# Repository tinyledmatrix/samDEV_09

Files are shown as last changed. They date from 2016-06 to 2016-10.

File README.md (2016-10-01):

# samDEV_09
small test/development board for Atmels's SAMD09 ARM Cortex M0+ Microcontroller

see my [poject](https://hackaday.io/project/12099) on Hackaday.io for more information. 

I build this board to getting started with the SAMD microcontroller family after I made the mistake to try the much bigger SAMD21 first. The SAMD09 used here is he smallest from this family and therefore has the shortest (still 709 p.) datasheet. I think this board will be, as my other microcontroller breakout boards, very useful for an early prototyping phase on breadboard. So far I quite like the SAMD09. If you compare it to the the ATmegas there are a lot more possibilities. Maybe this is the Arduino Nano killer for me.
Features

    - 3.3V 0.8A LDO (1117-3.3)
    - powered from USB, Vin pin (3.6-13.8V) or regulated 3.3V
    - on board USB to serial bride IC (CH340)
    - reset switch
    - SWD programming header
    - optional 32kHz crystal (if not needed pins can be used as additional IOs)
    - on board user LED (connected to PA02)
    - on board power LED (connected to 3.3 rail)

###Partlist:

    Part   Value        Package     Comment          
    A08                 0603        User LED connected to PA08
    C1     100n         C0603       
    C2     15p          C0603       optional 
    C3     15p          C0603       optional 
    C4     10n          C0603       
    C5     100n         C0603       
    C7     100n         C0603       
    D1     MBR0520LT    SOD123      power selection diode
    D2     MBR0520LT    SOD123      power selection diode
    IC1    CH340G       SOIC16      USB-UART bridge
    IC2    1117-3.3     SOT223      LDO
    JP1                 1X08_OCTA   pin header
    JP2                 1X08_OCTA   pin header
    JP5                 2X05_1,27B  programming pin header 
    K1     mini USB     generic     Mini USB connector
    PWR                 0603 	Power LED
    Q1     3215         3215        optional external 32kHz crystal 
    Q2     CSTCRCSTCE   CSTCESMALL  12 MHz resonator for CH340G
    R1     solder / 0   R0201       PA08 - pin header
    R2     solder / 0   R0201       PA09 - pin header
    R3     120  / 220   R0603       resistor for power LED
    R4     120  / 220   R0603       resistor for user LED
    R5     ~10k         R0603       pullup for reset
    S2                  SMDSWITCH   Chinese SMD switch
    U$1    SAMD09SOIC14 SO14        ARM Cortex M0+ microcontroller

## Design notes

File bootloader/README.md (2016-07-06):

Bootloader by Jeremy g. adapted to run also with my board. See also his [repository here](https://github.com/WeisTekEng/SamD09-Mini/).
For some documentation see [here](https://hackaday.io/project/12099-samdev09/log/41271)

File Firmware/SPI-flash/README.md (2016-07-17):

some early but working code to test/use SPI flash. Will get improved to a library version soon.
So far only tested with Macronix MX25L1005 1MBit (or 126kByte) flash
see this [project log](https://hackaday.io/project/12099-samdev09/log/42129-spi-flash-working) of my [project](https://hackaday.io/project/12099) on hackaday.io for more information. 

licensed under BSD 3-Clause License see also in the files

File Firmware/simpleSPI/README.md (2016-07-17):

some little basic files to use SERCOM0 for SPI. 

licensed under BSD 3-Clause License see also in the files

###How to use it:
in your main.c you must do some pin-pad multiplexing and call the functions. Also the 
slave select line is not handled by my library yet. You must do that in software. 
Here is one example 
```C
int main(void)
{
	uint8_t myVar;
	
	//do some other stuff
	
	// SPI setup (for pin_set_peripheral_function() see my uart library)
	pin_set_peripheral_function(PINMUX_PA14C_SERCOM0_PAD0); // mosi
	pin_set_peripheral_function(PINMUX_PA15C_SERCOM0_PAD1); // clk
	pin_set_peripheral_function(PINMUX_PA08D_SERCOM0_PAD2); // miso
	SPI_setup(3);
    PORT->Group[0].DIRSET.reg = PORT_PA02;      // pa02 as SW SS
    PORT->Group[0].OUTSET.reg = PORT_PA02;      // SS idle high
	
	//do some SPI stuff
	PORT->Group[0].OUTCLR.reg = PORT_PA02;		// SS low
    while(PORT->Group[0].OUT.reg & PORT_PA02);	// wait till SS is low
	myVar = SPI_RW_wait(0x42);
	PORT->Group[0].OUTSET.reg = PORT_PA02;		// SS high
	
	// do other stuff and some endless loop	
}
```

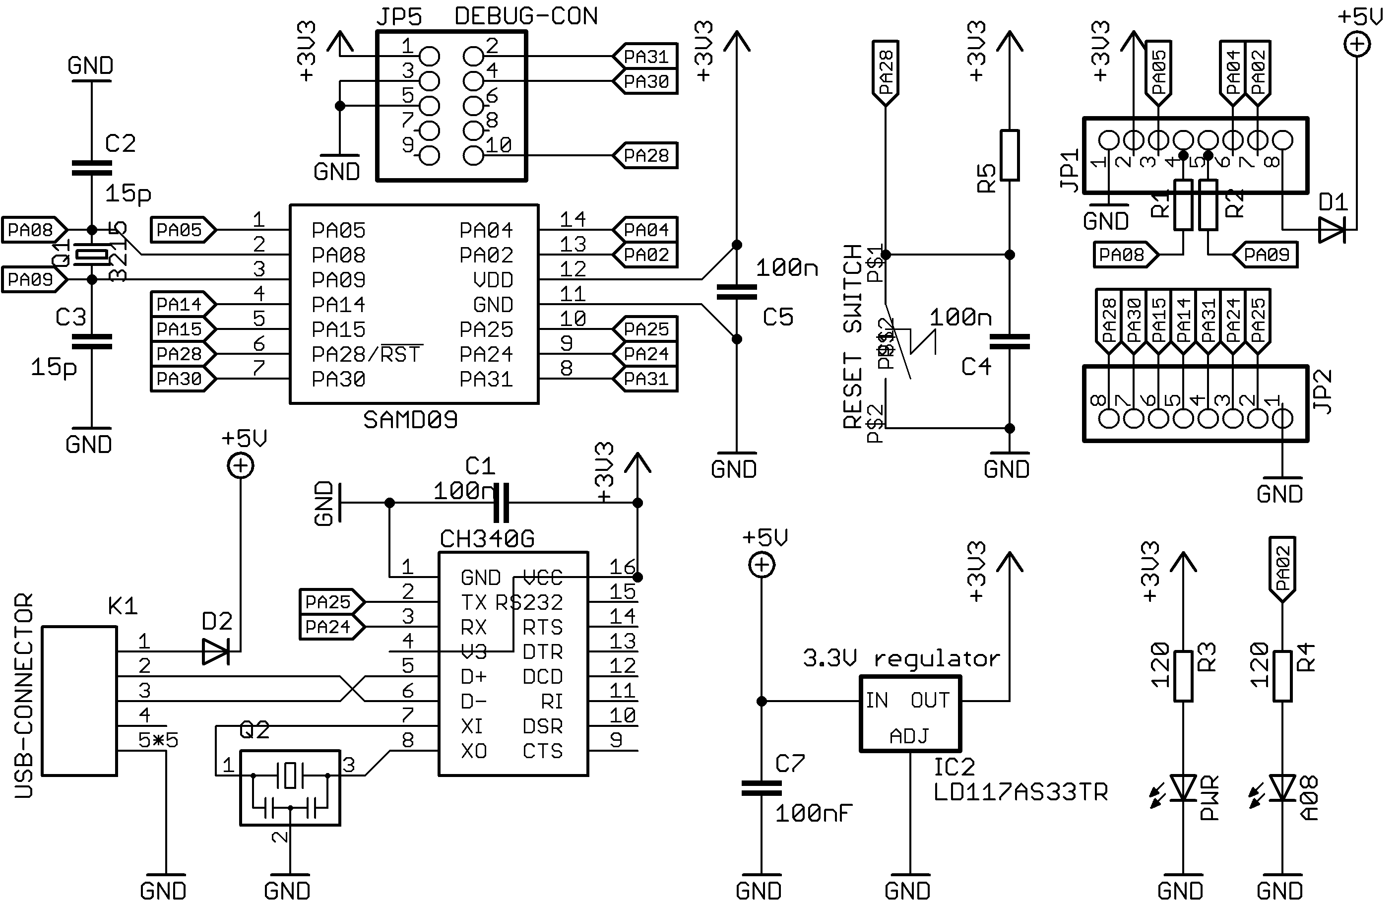
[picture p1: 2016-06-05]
schematic.png

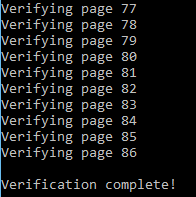
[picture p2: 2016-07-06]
bootloader/bootloader_R1_3_al1MOD/BootLoader/UART_Bootloader/Varify_Complete.PNG

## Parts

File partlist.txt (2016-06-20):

samDEV_09 Part list

Part   Value        Package     Comment
                    
A08                 0603        User LED connected to PA08
C1     100n         C0603       
C2     15p          C0603       optional (use only if external crystal used)
C3     15p          C0603       optional (use only if external crystal used)
C4     10n          C0603       
C5     100n         C0603       
C7     100n         C0603       
D1     MBR0520LT    SOD123      power selection diode
D2     MBR0520LT    SOD123      power selection diode
IC1    CH340G       SOIC16      USB-UART bridge
IC2    1117-3.3     SOT223      LDO
JP1                 1X08_OCTA   pin header
JP2                 1X08_OCTA   pin header
JP5                 2X05_1,27B  programming pin header 
K1     mini USB     generic     Mini USB connector
PWR                 0603 	   Power LED
Q1     3215         3215        optional external 32kHz crystal 
Q2     CSTCRCSTCE   CSTCESMALL  12 MHz resonator for CH340G
R1     solder / 0   R0201       solder jumper to connect PA08 to pin header
R2     solder / 0   R0201       solder jumper to connect PA09 to pin header
R3     120  / 220   R0603       resistor for power LED
R4     120  / 220   R0603       resistor for user LED
R5     ~10k         R0603       pullup for reset
S2                  SMDSWITCH   Chinese SMD switch
U$1    SAMD09SOIC14 SO14        Atmel SAMD09 ARM Cortex M0+ microcontroller

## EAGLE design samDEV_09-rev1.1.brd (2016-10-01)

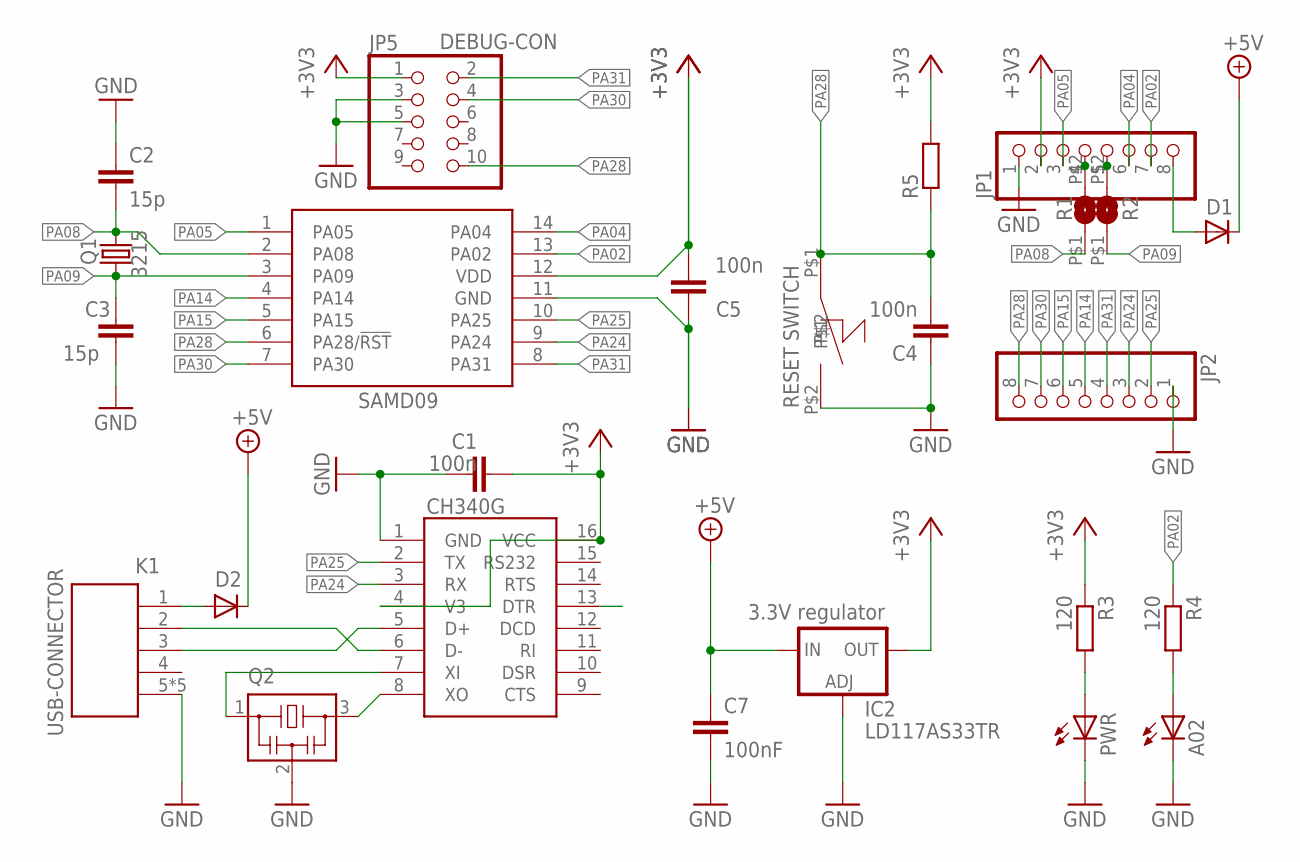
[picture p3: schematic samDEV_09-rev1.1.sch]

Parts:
A02: LEDCHIPLED_0603; CHIPLED_0603
C1, C4, C5: 100n; C0603
C2, C3: 15p; C0603
C7: 100nF; C0603
D1, D2: MBR0520LT; SOD123
IC1: CH340G; SOIC16
IC2: LD117AS33TR; SOT223
JP1, JP2: PINHD-1X8OCTA; 1X08_OCTA
JP5: PINHD-2X51272; 2X05_1,27B
K1: 629105136821
PWR: LEDCHIPLED_0603; CHIPLED_0603
Q1: 3215
Q2: CSTCRCSTCE_SMALL_FOOT; CSTCESMALL
R1, R2: SJAL; SMD_AL1
R3, R4: 120; R0603
R5: R-EU_R0603; R0603
S2: SMD_SWITCH; SMDSWITCH
U$1: SAMD09SOIC14; SO14

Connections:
+3V3: C1.2, C5.2, IC1.4 (V3), IC1.16 (VCC), IC2.2 (OUT), IC2.4 (OUT), JP1.2, JP5.1, R3.1, R5.2, U$1.12 (VDD)
+5V: C7.1, D1.C, D2.C, IC2.3 (IN)
GND: A02.C, C1.1, C2.1, C3.2, C4.1, C5.1, C7.2, IC1.1 (GND), IC2.1 (ADJ), JP1.1, JP2.1, JP5.3, JP5.5, K1.5, K1.Z1 (5), K1.Z2 (5), K1.Z3 (5), K1.Z4 (5), PWR.C, Q2.2, S2.P$2, U$1.11 (GND)
unnamed: D1.A, JP1.8
unnamed: D2.A, K1.1
unnamed: PWR.A, R3.2
unnamed: JP1.4, R1.P$2 (2)
unnamed: JP1.5, R2.P$2 (2)
unnamed: A02.A, R4.2
unnamed: IC1.6 (D-), K1.2
unnamed: IC1.5 (D+), K1.3
unnamed: IC1.8 (XO), Q2.3
unnamed: IC1.7 (XI), Q2.1
PA02: JP1.7, R4.1, U$1.13 (PA02)
PA04: JP1.6, U$1.14 (PA04)
PA05: JP1.3, U$1.1 (PA05)
PA08: C2.2, Q1.2, R1.P$1 (1), U$1.2 (PA08)
PA09: C3.1, Q1.1, R2.P$1 (1), U$1.3 (PA09)
PA14: JP2.5, U$1.4 (PA14)
PA15: IC1.13 (DTR), JP2.6, U$1.5 (PA15)
PA24: IC1.3 (RX), JP2.3, U$1.9 (PA24)
PA25: IC1.2 (TX), JP2.2, U$1.10 (PA25)
PA28: C4.2, JP2.8, JP5.10, R5.1, S2.P$1, U$1.6 (PA28/!RST)
PA30: JP2.7, JP5.4, U$1.7 (PA30)
PA31: JP2.4, JP5.2, U$1.8 (PA31)

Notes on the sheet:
SAMD09
DEBUG-CON
RESET SWITCH
USB-CONNECTOR
3.3V regulator

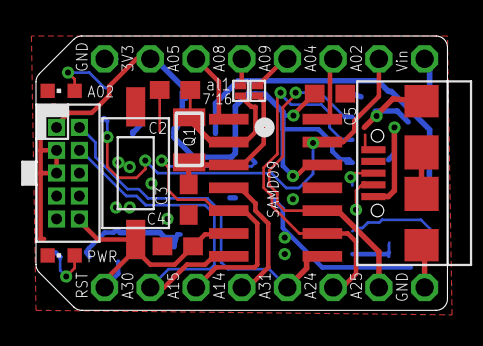
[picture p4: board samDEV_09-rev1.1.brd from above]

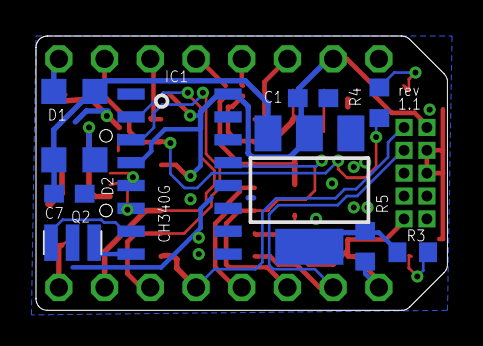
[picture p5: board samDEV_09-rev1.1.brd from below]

Board: 2 copper layers, 22.9 x 15.2 mm, 25 parts (10 on the bottom side), 25 nets.

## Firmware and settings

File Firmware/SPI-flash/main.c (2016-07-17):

/*
 * SAMD09_SPI-Flash
 * some dirty/qick and not well commented code to read/write SPI flash. 
 *
 * Created: 07-2016
 * Author : al1
 */ 
/*
Redistribution and use in source and binary forms, with or without modification, are 
permitted provided that the following conditions are met:

1. Redistributions of source code must retain the above copyright notice, this list of 
   conditions and the following disclaimer.

2. Redistributions in binary form must reproduce the above copyright notice, this list of 
   conditions and the following disclaimer in the documentation and/or other materials 
   provided with the distribution.

3. Neither the name of the copyright holder nor the names of its contributors may be used 
   to endorse or promote products derived from this software without specific prior written 
   permission.

THIS SOFTWARE IS PROVIDED BY THE COPYRIGHT HOLDERS AND CONTRIBUTORS "AS IS" AND ANY 
EXPRESS OR IMPLIED WARRANTIES, INCLUDING, BUT NOT LIMITED TO, THE IMPLIED WARRANTIES 
OF MERCHANTABILITY AND FITNESS FOR A PARTICULAR PURPOSE ARE DISCLAIMED. IN NO EVENT 
SHALL THE COPYRIGHT HOLDER OR CONTRIBUTORS BE LIABLE FOR ANY DIRECT, INDIRECT, INCIDENTAL, 
SPECIAL, EXEMPLARY, OR CONSEQUENTIAL DAMAGES (INCLUDING, BUT NOT LIMITED TO, PROCUREMENT 
OF SUBSTITUTE GOODS OR SERVICES; LOSS OF USE, DATA, OR PROFITS; OR BUSINESS INTERRUPTION) 
HOWEVER CAUSED AND ON ANY THEORY OF LIABILITY, WHETHER IN CONTRACT, STRICT LIABILITY, OR 
TORT (INCLUDING NEGLIGENCE OR OTHERWISE) ARISING IN ANY WAY OUT OF THE USE OF THIS SOFTWARE, 
EVEN IF ADVISED OF THE POSSIBILITY OF SUCH DAMAGE.
*/

#include "sam.h"
#include "simpleSPI.h"    
#include "uart.h"

//SPI flash commands:
#define FLASH_CMD_WRITE_ENABLE   0x06                     // set the write enable latch bit
#define FLASH_CMD_WRITE_DISABLE  0x04                     // reset the write enable latch bit
#define FLASH_CMD_READ_ID        0x9F                     // read the manufacturer ID and 2 byte device ID
#define FLASH_CMD_READ_STATUS    0x05                     // read the status register
#define FLASH_CMD_WRITE_STATUS   0x01                     // write to the status register
#define FLASH_CMD_READ_DATA      0x03 // + AD1 AD2 AD3       read n bytes until CS goes high
#define FLASH_CMD_FAST_READ_DATA 0x0b // + AD1 AD2 AD3 XX    XX:additional wait byte
#define FLASH_CMD_SECTOR_ERASE   0x20 // + AD1 AD2 AD3       Erase a sector
#define FLASH_CMD_BLOCK_ERASE    0xD8 // + AD1 AD2 AD3       Erase a block
#define FLASH_CMD_CHIP_ERASE     0x60                     // Erase the chip (alt comd: 0xC7) 
#define FLASH_CMD_PAGE_PROGRAM   0x02 // + AD1 AD3 AD3       program a page
#define FLASH_CMD_DEEP_PWR_DWN   0xB9                     // deep power down
#define FLASH_CMD_WEAKUP         0xAB                     // release from deep power down
#define FLASH_CMD_READ_E_ID      0xAB // + XX  XX  XX        read electronic ID
#define FLASH_CMD_READ_MAN_ID    0x90 // + XX  XX  ADD       read manufacturer and device ID
                              //                         ADD=0: manufacturer ID first
                              //                         ADD=1: device ID first
 /*
 Memory Organization:
 
 BLOCK | SECTOR |  ADDRESS RANGE
 ------+--------+----------------
       |   31   | 01F000 - 01FFFF
   1   |  ...   |       ...
       |   16   | 010000 - 010FFF
 ------+--------+----------------
       |   15   | 00F000 - 00FFFF
   2   |  ...   |       ...
       |    0   | 000000 - 000FFF
 
                                 
*/
 
void flash_set_SS(void)
 {
     PORT->Group[0].OUTCLR.reg = PORT_PA02;
     while(PORT->Group[0].OUT.reg & PORT_PA02);     
 }
 
void flash_reset_SS(void)
 {
     PORT->Group[0].OUTSET.reg = PORT_PA02;
 }
 
uint32_t flash_read_id(void)
{
    uint32_t ID;                    // Maufactorer ID [23:16]; device ID [15:0]
    flash_set_SS();                 // SS low
    SPI_RW_wait(FLASH_CMD_READ_ID); // read Id command
    ID  = SPI_RW_wait(0xFF)<<16;
    ID |= SPI_RW_wait(0xFF)<<8;
    ID |= SPI_RW_wait(0xFF);
    flash_reset_SS();               // SS high
    return ID;
} 

void flash_singleByteCommand(uint8_t cmd)
{
    flash_set_SS();
    SPI_RW_wait(cmd);
    flash_reset_SS();
}

uint8_t flash_read_status(void)
{
    uint8_t status;
    flash_set_SS();
    SPI_RW_wait(FLASH_CMD_READ_STATUS);
    status=SPI_RW_wait(0xFF);
    flash_reset_SS();
    return status;
}

void flash_chip_erase(void)
{
    flash_singleByteCommand(FLASH_CMD_WRITE_ENABLE);
    flash_singleByteCommand(FLASH_CMD_CHIP_ERASE);
    while (flash_read_status() & 1);                // wait for wrtie to get ready.
}

void flash_page_program(uint32_t address, uint8_t data[])
{
    flash_singleByteCommand(FLASH_CMD_WRITE_ENABLE);
    flash_set_SS();     // SS_LOW
    SPI_RW_wait(FLASH_CMD_PAGE_PROGRAM);
    SPI_RW_wait(address>>16);   // address MSB
    SPI_RW_wait(address>>8);
    SPI_RW_wait(address);
    for (uint16_t i=0; i<=255; i++)
        SPI_RW_wait(data[i]);
    flash_reset_SS();
    flash_singleByteCommand(FLASH_CMD_WRITE_DISABLE);
    while(flash_read_status() & 1);     // wati to get ready       
}

void flash_drity_read(uint32_t address, uint8_t data[], uint16_t dataLength)
{
    flash_set_SS();
    SPI_RW_wait(FLASH_CMD_READ_DATA);
    SPI_RW_wait(address>>16);   // address MSB
    SPI_RW_wait(address>>8);
    SPI_RW_wait(address);
    for (uint16_t i=0; i<dataLength; i++)
        data[i]=SPI_RW_wait(0xFF);
    flash_reset_SS();
}    

void flash_write_status(uint8_t newStatus)
{
    flash_set_SS();
    SPI_RW_wait(FLASH_CMD_WRITE_STATUS);
    SPI_RW_wait(newStatus);
    flash_reset_SS();
}

// very useful function. At least this version was written by me based on some code found somewhere on line (forgot where) 
void pin_set_peripheral_function(uint32_t pinmux)
{
    /* the variable pinmux consist of two components:
        31:16 is a pad, wich includes:
            31:21 : port information 0->PORTA, 1->PORTB
            20:16 : pin 0-31
        15:00 pin multiplex information
        there are defines for pinmux like: PINMUX_PA09D_SERCOM2_PAD1 
    */
    uint16_t pad = pinmux >> 16;    // get pad (port+pin)
    uint8_t port = pad >> 5;        // get port
    uint8_t pin  = pad & 0x1F;      // get number of pin - no port information anymore
    
    PORT->Group[port].PINCFG[pin].bit.PMUXEN =1;
    
    /* each pinmux register is for two pins! with pin/2 you can get the index of the needed pinmux register
       the p mux resiter is 8Bit   (7:4 odd pin; 3:0 evan bit)  */
    // reset pinmux values.                             VV shift if pin is odd (if evan:  (4*(pin & 1))==0  )
    PORT->Group[port].PMUX[pin/2].reg &= ~( 0xF << (4*(pin & 1)) );
                    //          
    // set new values
    PORT->Group[port].PMUX[pin/2].reg |=  ( (uint8_t)( (pinmux&0xFFFF) <<(4*(pin&1)) ) ); 
}

void printHEX(uint8_t buffer)
{
    uint8_t buffer2=(buffer & 0xF0)>>4;// high digit
    UART_sercom_simpleWrite(SERCOM1, (buffer2>9)?('A'+buffer2-10):('0' + buffer2) );
    buffer2=buffer & 0xF;              // low digit
    UART_sercom_simpleWrite(SERCOM1, (buffer2>9)?('A'+buffer2-10):('0' + buffer2) );
}

int main(void)
{
    // create test page buff
    uint8_t myPage[256];
    for (uint16_t i=0; i<=255; i++)
        myPage[i]=i;
        
    uint8_t flashReadBuffer[255];
    
    /* Initialize the SAM system */
    SystemInit();

    uint8_t buffer=0xFF;
	uint8_t buffer2=0xFF;
    uint32_t flashID=0;
	
	pin_set_peripheral_function(PINMUX_PA14C_SERCOM0_PAD0); // mosi
	pin_set_peripheral_function(PINMUX_PA15C_SERCOM0_PAD1); // clk
	pin_set_peripheral_function(PINMUX_PA08D_SERCOM0_PAD2); // miso
	SPI_setup(3);
    PORT->Group[0].DIRSET.reg = PORT_PA02;      // pa as sw ss
    PORT->Group[0].OUTSET.reg = PORT_PA02;      // SS idle high
    
	
	pinMux(PINMUX_PA24C_SERCOM1_PAD2); // SAMD09 TX
	pinMux(PINMUX_PA25C_SERCOM1_PAD3); // SAMD09 RX
	UART_sercom_init(SERCOM1);
	
	UART_sercom_simpleWrite(SERCOM1, 'H');
	UART_sercom_simpleWrite(SERCOM1, 'e');
	UART_sercom_simpleWrite(SERCOM1, 'l');
	UART_sercom_simpleWrite(SERCOM1, 'l');
	UART_sercom_simpleWrite(SERCOM1, 'o');
	UART_sercom_simpleWrite(SERCOM1, '!');
	UART_sercom_simpleWrite(SERCOM1, 0xa);
		
	buffer=SPI_RW_wait(0xAA);
	SPI_RW_wait(buffer);
	
	SPI_write_wait('!');
	SPI_write_wait('!');
    SPI_flush_RXBuffer();
    
    flashID=flash_read_id();
    buffer=flashID>>16;         // buffer= Manufacturer ID [23:16]
    flashID&=0xFFFF;            // mask device ID
    
    UART_sercom_simpleWrite(SERCOM1, 'M');
    UART_sercom_simpleWrite(SERCOM1, 'I');
    UART_sercom_simpleWrite(SERCOM1, 'D');
    UART_sercom_simpleWrite(SERCOM1, ':');
    printHEX(buffer);
    UART_sercom_simpleWrite(SERCOM1, ' ');
    UART_sercom_simpleWrite(SERCOM1, 'D');
    UART_sercom_simpleWrite(SERCOM1, 'I');
    UART_sercom_simpleWrite(SERCOM1, 'D');
    UART_sercom_simpleWrite(SERCOM1, ':');
    printHEX(flashID>>8);
    printHEX(flashID);
    UART_sercom_simpleWrite(SERCOM1, 0xa);
    
    flash_read_status();
    flash_write_status(0);
    flash_read_status();
    buffer=1;                       // for some delay I think no delay needed. But this makes the reading in the logic analyzer easier
    while(buffer++);
    buffer=1;
    while(buffer++);
    
    flash_chip_erase();
    buffer=1;
    while(buffer++);
    buffer=1;
    while(buffer++);
    
    flash_page_program(0xf000, myPage);     // write myPage to page starting at adress 0xF000
    buffer=1;
    while(buffer++);
    buffer=1;
    while(buffer++);
    
    flash_drity_read(0xf00f, flashReadBuffer, 255);
	
    while (1) 
    {
        flashID++;  //flashID just reused
// 		if (UART_sercom_getByte(SERCOM1, &buffer))	// if uart received
// 		{
// 			buffer2=SPI_RW_wait(buffer);
// 			UART_sercom_simpleWrite(SERCOM1, buffer2);
// 		}
        if (flashID%5000==0)
            PORT->Group[0].OUTTGL.reg=PORT_PA02;    // blink !SS line - on baord led if using my samDEV_09 board
    }
}

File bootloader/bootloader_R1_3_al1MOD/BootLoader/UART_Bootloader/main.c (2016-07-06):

/*
 * main.c
 *Project:			miniSam USART bootloader.
 *Author:			Weistek Engineering (jeremy G.)
 *                  and some minor changes by al1
 *website:			www.weistekengineering.com
                    https://hackaday.io/project/12099 for al1's sam09 board
 *date:				06-29-2016
 *Summery:			Modified version of the Samd10 bootloader.
 *					If PA15 bootpin is held low, micro will enter USART bootloader mode.
 *					if PA15 is high, micro runs user program if there is one at new start
 *					memory. Look at APP_START for start location of user flash.
 *
 *License:	        GNU GENERAL PUBLIC LICENSE Version 3 or newer. The header of this file may not change.
 *
 *					unless new features are added then the update section may be updated. The License file in 
 *					the root of this repo Trunk/LICENSE should have been provided to you. If it was not you may 
 *					find a copy of the GNU Open source license at https://www.gnu.org/licenses/gpl.html
 *
 *Modified:			07/04/2016
 *
 *Important pins : 	UART pins [PA25 PAD3 -> TXd, PA24 PAD2 -> RXd]
 *					Boot En Pin PA15: enabled boot on reset when DTR pin LOW. Change to PA27?
 *					USART reset pin -> RTS -> RST PIN#. Used to reset the micro when
 *					Serial is plugged in, pulse RTS LOW. Almost arduino esqe.
 *
 *Update:			fixed write_nvm function, would fall to dummy handler.
 *
 *Todo:				clean up code, reduce bootloader size. fix a few things (noted in head).
 *					clean up and finish the python front end for loading new programs.
 *
 *Update:			7/04/2016, Thanks to Philip of Oshchip I was able to get this bootloader working.
 *					Bootloader now starts the new app at 0x800, any program built will need there starting
 *					address changed from 0x000 to 0x800. Use the included samd09d14a_flash.ld file for this.
 *					the modification is already present in that file.
 *
 *update:			07/04/2016 Made some progress with the verification loop. it now addresses the proper nvm space.
 *					I think its putting garbage on the uart line in the last bit. the python script says the device is 
 *					not responding, it is its just not sending an s like the python script wants instead its sending the 
 *					same omega symbol..
 *
 *update:			07/05/2016 fixed the verification issue, made the for loop smaller as well. learned a lot about pointers.
 *					as of now this is the final version of the boot loader V1.2, until I find a need to upgrade it
 *					to work with another IDE such as the arduino IDE. <- may be sometime soon. 
 *
 *update:			07/06/2016 cleaned up code, added special talk for new front end.
 *
 *update:           2016-07-06 by al1   - changed aVER-Array to fit to my samDEV_09 board
                                        - added define for the BOOTLED and set value to 02 (Porta02 used for LED) was 
                                          hard coded as 14 before
                                        - changed pull resistor on BOOT_PIN from pulldown to pullup
 */ 


#include "sam.h"

#define bool	_Bool
#define PORTA 0 //Samd09 only has one port Port0

/* Change the following if different SERCOM and boot pins are used */
#define BOOT_SERCOM			SERCOM1		//miniSam uses Sercom1 for USART
#define BOOT_SERCOM_BAUD	115200
#define BOOT_PORT			PORTA
#define BOOT_PIN			15 //14		//PA15 for bootloader en, toggled by the python script. or DTR from serial coms.

#define BOOTLED 02                      //bootled on PA02

#define div_ceil(a,b)(((a)+(b)-1)/(b))			//extracted function from samd_math.h <- something like that.

/* SERCOM USART GCLK Frequency */
#define SERCOM_GCLK		8000000UL		//processor speed.
#define BAUD_VAL	(65536.0*(1.0-((float)(16.0*(float)BOOT_SERCOM_BAUD)/(float)SERCOM_GCLK))) //calculate baud rate from SERCOM_GCLK

/* Application starts from 1kB memory - Bootloader size is 1kB */
/* Change the address if higher boot size is needed */
/*good site for quick conversions.*/
/*http://www.binaryhexconverter.com/hex-to-decimal-converter*/
#define APP_START	0x00000800 //This gives 1536 bytes of bootloader space.

/* Target application size can be 15kB */
/* APP_SIZE is the application section size in kB */
/* Change as per APP_START */
#define APP_SIZE	5	//This is how much flash memory is left for the application.

/* Memory pointer for flash memory */
#define NVM_MEMORY			((volatile uint16_t *)FLASH_ADDR)

/** If \c false, a page write command will be issued automatically when the
*  page buffer is full. */
bool manual_page_write;

uint8_t data_8 = 1;
uint32_t file_size, i, dest_addr;
uint32_t volatile app_start_address;
uint8_t volatile data_from_flash;
uint32_t *flash_ptr;
uint8_t *flash_byte_ptr;

uint8_t specialTalk = 0;

//Version information.
uint8_t aVER[78] = {'s','a','m','D','E','V','_','0','9',' ',' ',' ',' ','\n',
                    'b','o','o','t','l','o','a','d','e','r',' ','V','1','.','2','\n',
					'D','e','v',' ','B','o','a','r','d',' ','r','e','g','i','s','t','e','r',
					'e','d',' ','t','o',' ','a','l','e','x',' ','a','l','1','\n',
					'B','o','a','r','d',' ','I','D',' ','0','x','0','0','1','\n'};

void setup_ptrs()
{
	//set values, for flash pointers.
	dest_addr = APP_START;
	flash_ptr = APP_START;
	app_start_address = *flash_ptr;
	flash_byte_ptr = APP_START;
}

/*pin pad setup for SERCOM1 and USART*/
static inline void pin_set_peripheral_function(uint32_t pinmux)
{
    /* the variable pinmux consist of two components:
        31:16 is a pad, witch includes:
            31:21 : port information 0->PORTA, 1->PORTB
            20:16 : pin 0-31
        15:00 pin multiplex information
        there are defines for pinmux like: PINMUX_PA09D_SERCOM2_PAD1 
    */
    uint16_t pad = pinmux >> 16;    // get pad (port+pin)
    uint8_t port = pad >> 5;        // get port
    uint8_t pin  = pad & 0x1F;      // get number of pin - no port information anymore
    
    PORT->Group[port].PINCFG[pin].bit.PMUXEN =1;
    
    /* each pinmux register is for two pins! with pin/2 you can get the index of the needed pinmux register
       the p mux resiter is 8Bit   (7:4 odd pin; 3:0 evan bit)  */
    // reset pinmux values.                             VV shift if pin is odd (if evan:  (4*(pin & 1))==0  )
    PORT->Group[port].PMUX[pin/2].reg &= ~( 0xF << (4*(pin & 1)) );
                    //          
    // set new values
    PORT->Group[port].PMUX[pin/2].reg |=  ( (uint8_t)( (pinmux&0xFFFF) <<(4*(pin&1)) ) ); 
}
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

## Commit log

2016-06-05 added schematic
2016-06-19 added UART example
2016-06-19 replaced taps with spaces
    [UART_test.c]
2016-07-16 added SPI libary
2016-07-17 updated SPI readme
    mow there is some example code in the SPI readme how to use rhis library
2016-07-17 readme SPI
2016-07-17 added spi-flash stuff
    some early code for spi flash
2016-07-25 SPI update
    now also working with clocks, which are not the default 1MHz
2016-10-01 Added gerbersof rev1.1
2016-10-01 eagle files of rev 1.1
    [samDEV_09-rev1.1.brd, samDEV_09-rev1.1.sch]

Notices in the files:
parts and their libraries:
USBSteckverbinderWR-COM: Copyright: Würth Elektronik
